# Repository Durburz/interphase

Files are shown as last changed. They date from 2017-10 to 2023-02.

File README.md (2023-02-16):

# interphase

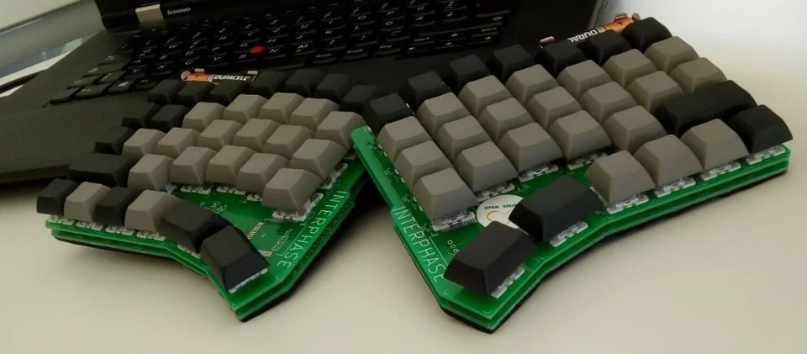
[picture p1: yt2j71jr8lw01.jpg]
keyboard picture layout


interphase is a open-source mechanical keyboard.
Kudos to reversebias, as I got inspired by his fascinating mitosis keyboard (https://github.com/reversebias/mitosis-hardware).
The only problem was the lack of keys for a full german layout + number row.

Therefor, interphase is a kind of ISO-compatible layout with some minor modifications.

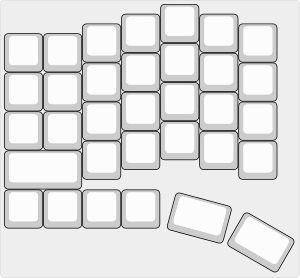
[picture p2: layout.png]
keyboard layout layout


Update on battery life: The AAA batteries (Duracell) per keyboard-half are still going strong. After 5 months of heavy usage at work, they only dropped to ~1.4V. Therefor the total lifetime of the batteries will be approximateley 1 - 1.5 years, as the voltage regulator will work down to 0.35V.

As identified in https://github.com/Durburz/interphase-firmware/issues/6 it is strictly necessary to use the C variant of the MCP1640

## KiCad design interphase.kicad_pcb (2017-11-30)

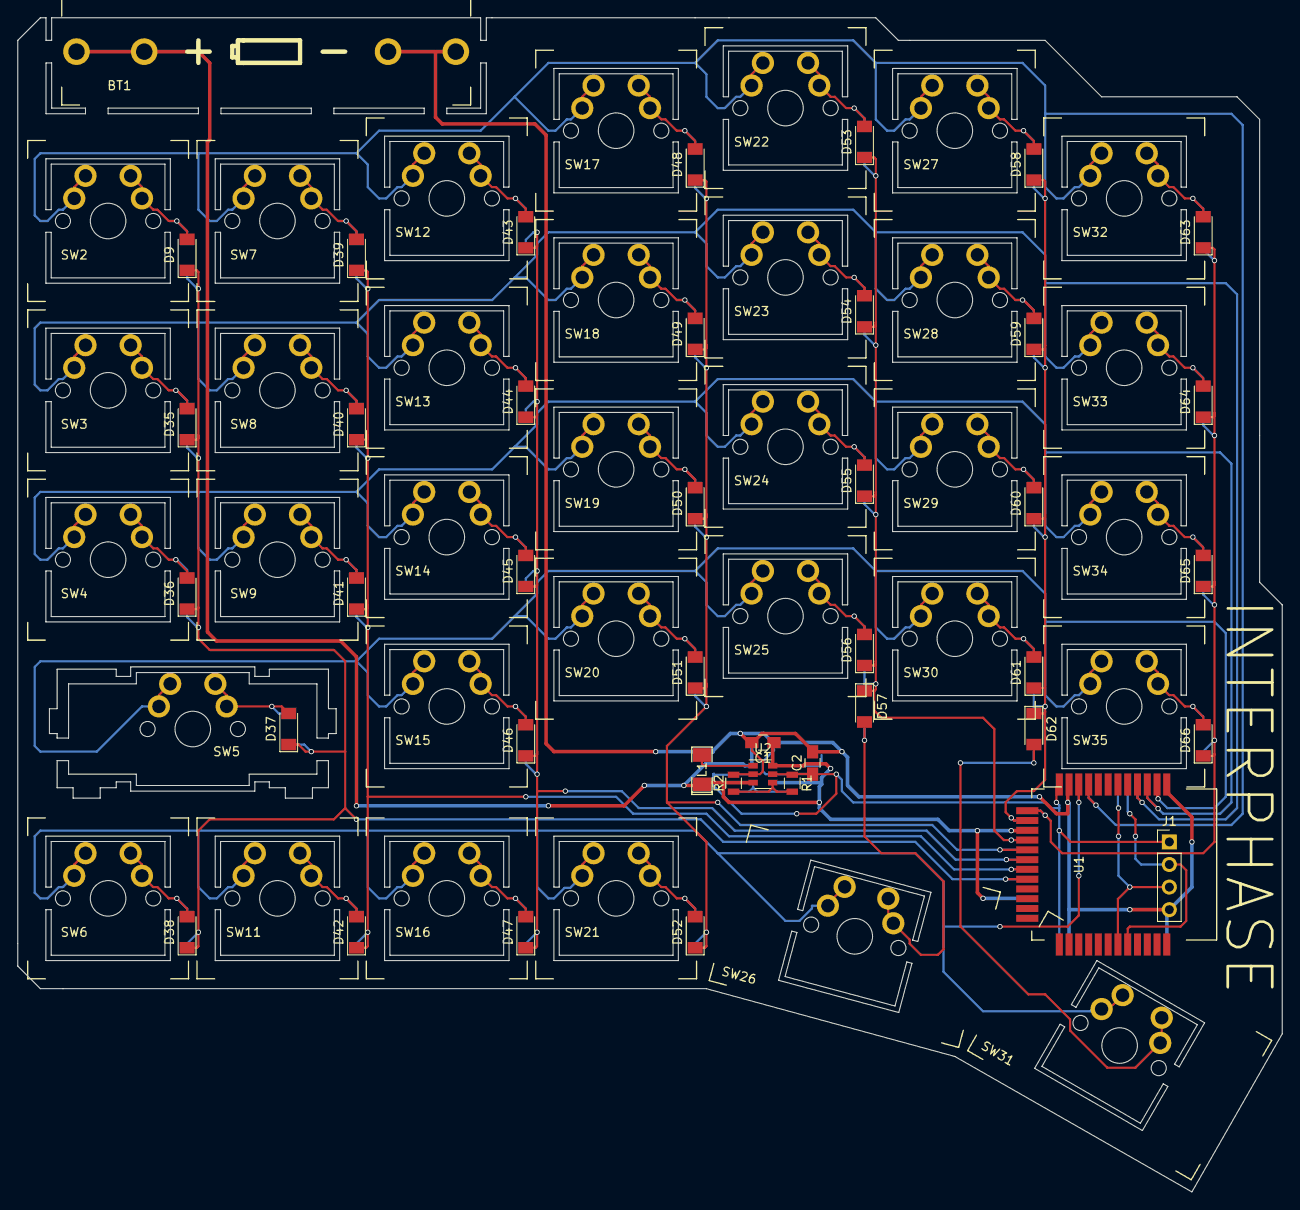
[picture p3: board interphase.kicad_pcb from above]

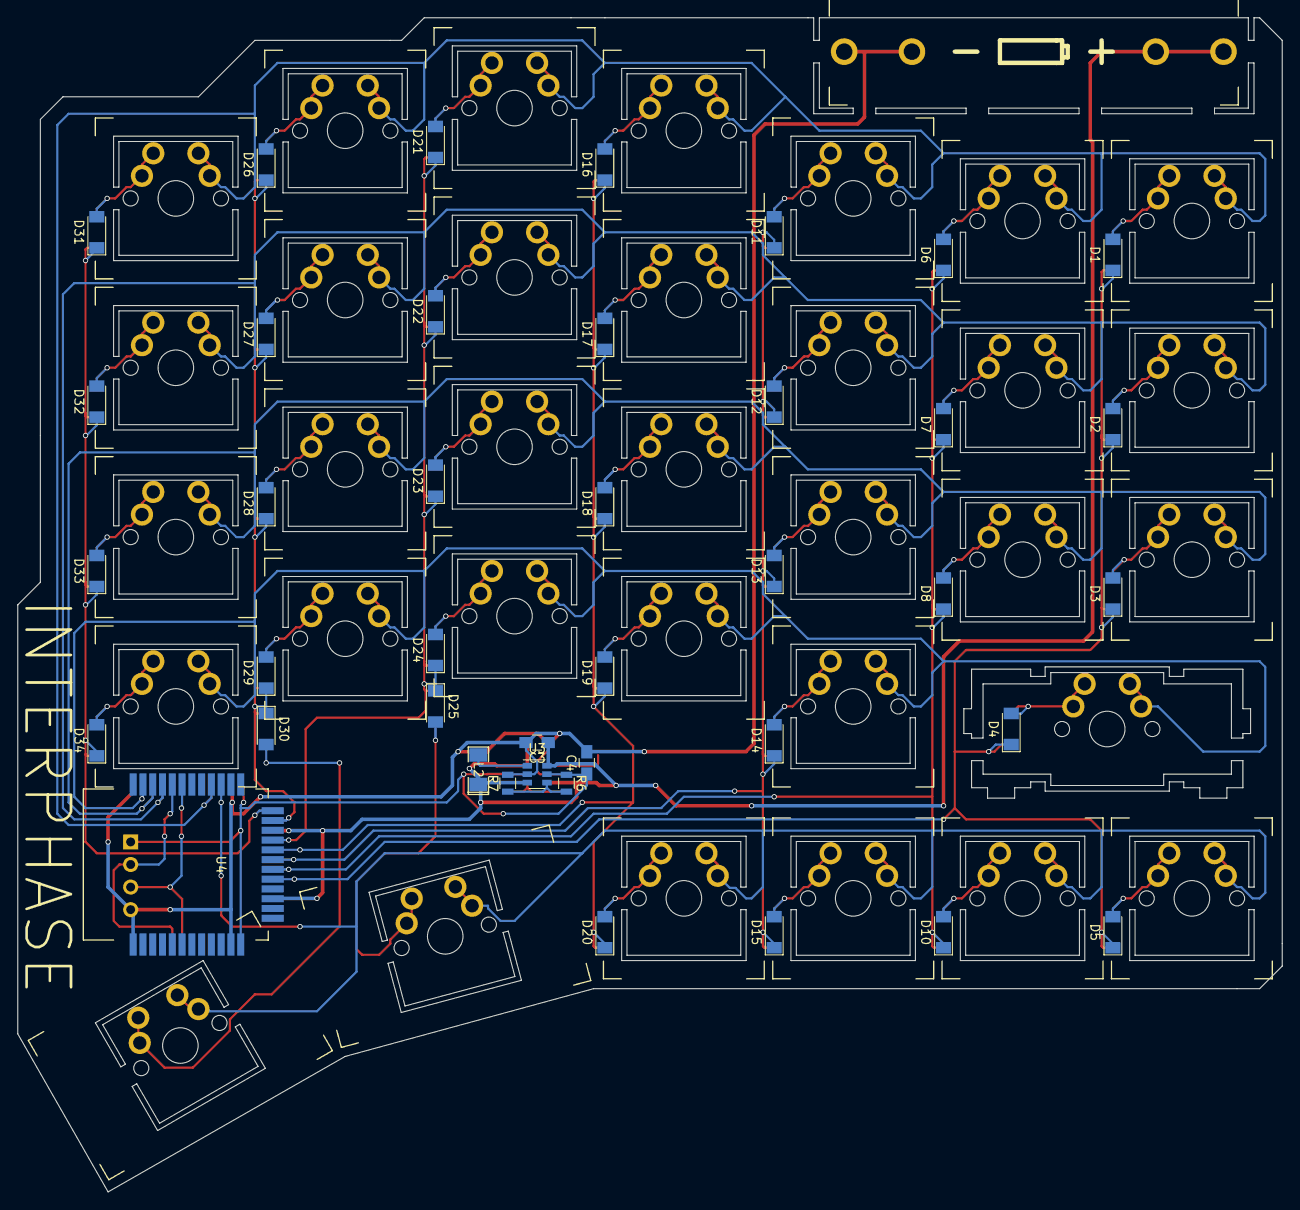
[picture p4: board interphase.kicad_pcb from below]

Board: 2 copper layers, 142.2 x 132.1 mm, 115 parts (40 on the bottom side), 54 nets.

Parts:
BT1: Battery_Cell; KEYSTONE-82_AAA_battery-clip
C1, C3: 4,7µF; C_0805_HandSoldering
C2, C4: 10µF; C_0805_HandSoldering
D1, D2, D3, D4, D5, D6, D7, D8, D9, D10, D11, D12, D13, D14, D15, D16, D17, D18, D19, D20, D21, D22, D23, D24, D25, D26, D27, D28, D29, D30, D31, D32, D33, D34, D35, D36, D37, D38, D39, D40, D41, D42, D43, D44, D45, D46, D47, D48, D49, D50, D51, D52, D53, D54, D55, D56, D57, D58, D59, D60, D61, D62, D63, D64, D65, D66: D; D_MiniMELF
J1: Conn_01x04_Male; Pin_Header_Straight_1x04_Pitch2.54mm
L1, L2: 4,7µH; SMD-1206_Pol
R1, R6: 536K; R_0805
R2, R7: 309K; R_0805
SW2, SW3, SW4, SW6, SW7, SW8, SW9, SW11, SW12, SW13, SW14, SW15, SW16, SW17, SW18, SW19, SW20, SW21, SW22, SW23, SW24, SW25, SW27, SW28, SW29, SW30, SW32, SW33, SW34, SW35: MOM-SPST; CHERRY-MX_double_bo_nodiode
SW5: MOM-SPST; CHERRY-MX_double_bo_2u_nodiode
SW26, SW31: MOM-SPST; CHERRY-MX_double_bo_1_5u
U1, U4: Core51822B; Core51822(B)
U2, U3: MCP1640; SOT-23-6

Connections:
+3V3: C2.1, C4.1, J1.1, R1.1, R6.1, U1.12, U2.5, U3.5, U4.12
+BATT: BT1.1, C1.1, C3.1, L1.1, L2.1, U1.15, U2.3, U2.6, U3.3, U3.6, U4.15
GND: BT1.2, C1.2, C2.2, C3.2, C4.2, J1.4, R2.2, R7.2, U1.1, U1.11, U2.2, U3.2, U4.1, U4.11
unnamed: D1.1, D2.1, D3.1, D4.1, D5.1, U1.20, U4.17
unnamed: D1.2, D9.2, SW2.2
unnamed: D2.2, D35.2, SW3.2
unnamed: D3.2, D36.2, SW4.2
unnamed: D6.1, D7.1, D8.1, D10.1, U1.19, U4.18
unnamed: D10.2, D42.2, SW11.2
unnamed: D11.1, D12.1, D13.1, D14.1, D15.1, U1.18, U4.19
unnamed: D11.2, D43.2, SW12.2
unnamed: D12.2, D44.2, SW13.2
unnamed: D13.2, D45.2, SW14.2
unnamed: D14.2, D46.2, SW15.2
unnamed: D15.2, D47.2, SW16.2
unnamed: D16.1, D17.1, D18.1, D19.1, D20.1, U1.17, U4.20
unnamed: D16.2, D48.2, SW17.2
unnamed: D17.2, D49.2, SW18.2
unnamed: D18.2, D50.2, SW19.2
unnamed: D19.2, D51.2, SW20.2
unnamed: D20.2, D52.2, SW21.2
unnamed: D21.1, D22.1, D23.1, D24.1, D25.1, U1.16, U4.21
unnamed: D21.2, D53.2, SW22.2
unnamed: D22.2, D54.2, SW23.2
unnamed: D23.2, D55.2, SW24.2
unnamed: D24.2, D56.2, SW25.2
unnamed: D25.2, D57.2, SW26.2
unnamed: D26.1, D27.1, D28.1, D29.1, D30.1, U1.14, U4.23
unnamed: D26.2, D58.2, SW27.2
unnamed: D27.2, D59.2, SW28.2
unnamed: D28.2, D60.2, SW29.2
unnamed: D29.2, D61.2, SW30.2
unnamed: D30.2, D62.2, SW31.2
unnamed: D31.1, D32.1, D33.1, D34.1, U1.13, U4.24
unnamed: D31.2, D63.2, SW32.2
unnamed: D32.2, D64.2, SW33.2
unnamed: D33.2, D65.2, SW34.2
unnamed: D34.2, D66.2, SW35.2
unnamed: D4.2, D37.2, SW5.2
unnamed: D5.2, D38.2, SW6.2
unnamed: D6.2, D39.2, SW7.2
unnamed: D7.2, D40.2, SW8.2
unnamed: D8.2, D41.2, SW9.2
unnamed: J1.2, U1.32, U4.32
unnamed: J1.3, U1.31, U4.31
unnamed: L1.2, U2.1
unnamed: L2.2, U3.1
unnamed: R1.2, R2.1, U2.4
unnamed: R6.2, R7.1, U3.4
unnamed: SW6.1, SW11.1, SW16.1, SW21.1, SW26.1, SW31.1, U1.10, U4.27
unnamed: SW2.1, SW7.1, SW12.1, SW17.1, SW22.1, SW27.1, SW32.1, U1.9, U4.28
unnamed: SW3.1, SW8.1, SW13.1, SW18.1, SW23.1, SW28.1, SW33.1, U1.4, U4.33
unnamed: SW4.1, SW9.1, SW14.1, SW19.1, SW24.1, SW29.1, SW34.1, U1.3, U4.34
unnamed: SW5.1, SW15.1, SW20.1, SW25.1, SW30.1, SW35.1, U1.2, U4.35

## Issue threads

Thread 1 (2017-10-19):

firmware ？

YCF, 2017-10-19:
I found that the matrix of your keyboard is different from the mitosis, you are using the matrix scan method just like the common keyboard. Do you have the firmware of this keyboard?

Durburz, 2017-10-19:
Yeah, due to the fact, that there are too few IO ports at the nrf51822 I had to use a matrix design.
I'm going to start working on the firmware, when my prototype PCB arrives.

But I think I won't go reversebias' way of using QMK and a receiver. Instead i'm going to make a BLE HID firmware.

Durburz, 2017-11-30:
Modified Mitosis firmware for matrix scanning as requested can be found here:
https://github.com/Durburz/interphase-firmware

YCF, 2017-12-01:
Good job!
Thank you.

jhbruhn, 2021-11-14:
"Instead i'm going to make a BLE HID firmware."
I am wondering, did that ever happen? :)

Durburz, 2021-11-14:
No, this didn't happen on my side. But [here](https://github.com/joric/bluetosis) is a bluetooth firmware for the pretty similar mitosis keyboard.

Closed 2017-10-21.

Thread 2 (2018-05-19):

Libraries missing

lemmi, 2018-05-19:
Hi,
wanted to check out the project, but a couple of libs seem to be missing.

* `kicad_lib` (actually found that on your github, but it used an absolute path)
* `kicad-library-master/library/switches`
* `kicadlib-master/library/mcp1640`

It would be awesome if you made them available or could point me to where they are available. Thanks :)

Durburz, 2018-05-23:
Hi,
sorry for the inconvenience, here are the libraries for now. I'll set them up as submodules next week.
https://github.com/oyvindt/kicadlib (mcp1640)
https://github.com/bfrigon/kicad-library (switches)

lemmi, 2018-05-23:
perfect, thank you :)

Durburz, 2018-05-30:
Kicad libraries are now added as git submodules.

Now it is just needed to go into the lib/*submodule* folders and execute
``git submodule init
git submodule update``

Closed 2018-05-30.

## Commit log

2017-09-19 schematic preversion and layout preversion
    [interphase.kicad_pcb, interphase.sch]
2017-09-21 some work
    [interphase.kicad_pcb, interphase.sch]
2017-09-27 repositioning and routing
    [interphase.kicad_pcb]
2017-09-28 more routing
    [interphase.kicad_pcb]
2017-10-05 finish routing
    [interphase.kicad_pcb]
2017-11-30 finish layout and fix prototype issues
    [interphase.kicad_pcb, interphase.sch]
2018-05-30 added kicad libraries as submodules
